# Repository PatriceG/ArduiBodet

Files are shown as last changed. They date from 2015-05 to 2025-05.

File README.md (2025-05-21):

# ArduiBodet	
Horloge mère pour Horloge de type *Bodet 1/2 Minute* pilotée par Arduino

Ce code nécessite les librairies suivantes:
  -DS3231 : [http://m5.img.dxcdn.com/CDDriver/CD/sku.222910.rar](http://m5.img.dxcdn.com/CDDriver/CD/sku.222910.rar)
  -Low-Power: [https://github.com/rocketscream/Low-Power] (https://github.com/rocketscream/Low-Power)
  
L'IDE utilisé est **AtmelStudio + VisualMicro** mais le code est compatible avec l'IDE Arduino.

Les détails de la construction de l'horloge mère sont donnés ici: [http://breizhmakers.over-blog.com/tag/horlogebodet/](http://breizhmakers.over-blog.com/tag/horlogebodet/)

# Les objectifs fixés sont: 

- Faible coût
- Alimentation 9V (nécessaire pour piloter l'horloge)
- Application automatique des changements d'heure.
- Très bonne stabilité de l'horloge (2 ppm soit environ 1 minute/an)
- Interrupteur Marche/Arrêt
- Interrupteur de mise en mode avance rapide pour mise à l'heure.

# Comment Flasher le Firmware

La plupart des ATMega328 sont livrés configurés pour fonctionner avec un quartz externe à 16MHz.

Avant de pouvoir flasher le firmware il faut donc installer l'ATMega sur une Breadboard en y câblant un quartz 16MHz et ses condensateurs associés, et y brancher le programmateur (j'utilise un USBAsp).

J'ai ensuite suivi [cette doc](https://www.electrosoftcloud.com/en/changing-the-arduino-clock-speed/) avec un IDE Arduino 1.8.18, mais cela fonctionne aussi avec l'IDE Arduino 2.x, pour configurer l'Arduino en mode horloge interne 1MHz (ou 8MHz, ça fonctionne aussi).

Une fois les définitions de Board MiniCore installées et choisi ATMega328 on a accès à tout un tas de settings, dont le mode de fonctionnement de l'horloge. 
Il reste ensuite à cliquer sur "Graver la séquence d'initialisation" pour flasher cette config de fuses (avec le programmateur choisi. J'utilise un USBAsp).

Il est ensuite conseillé de flasher le sketch Blink et de vérifier que la pin correspondant à D13 clignotte bien à 1 Hz

On peut alors flasher le sketch de l'Horloge.

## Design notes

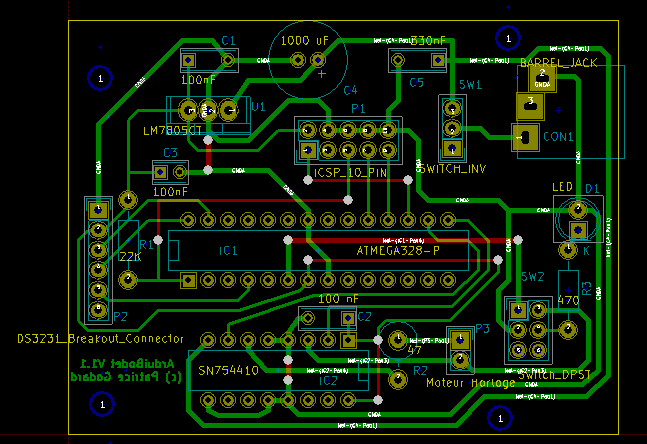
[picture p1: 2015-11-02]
doc/Screenshot du circuit.png

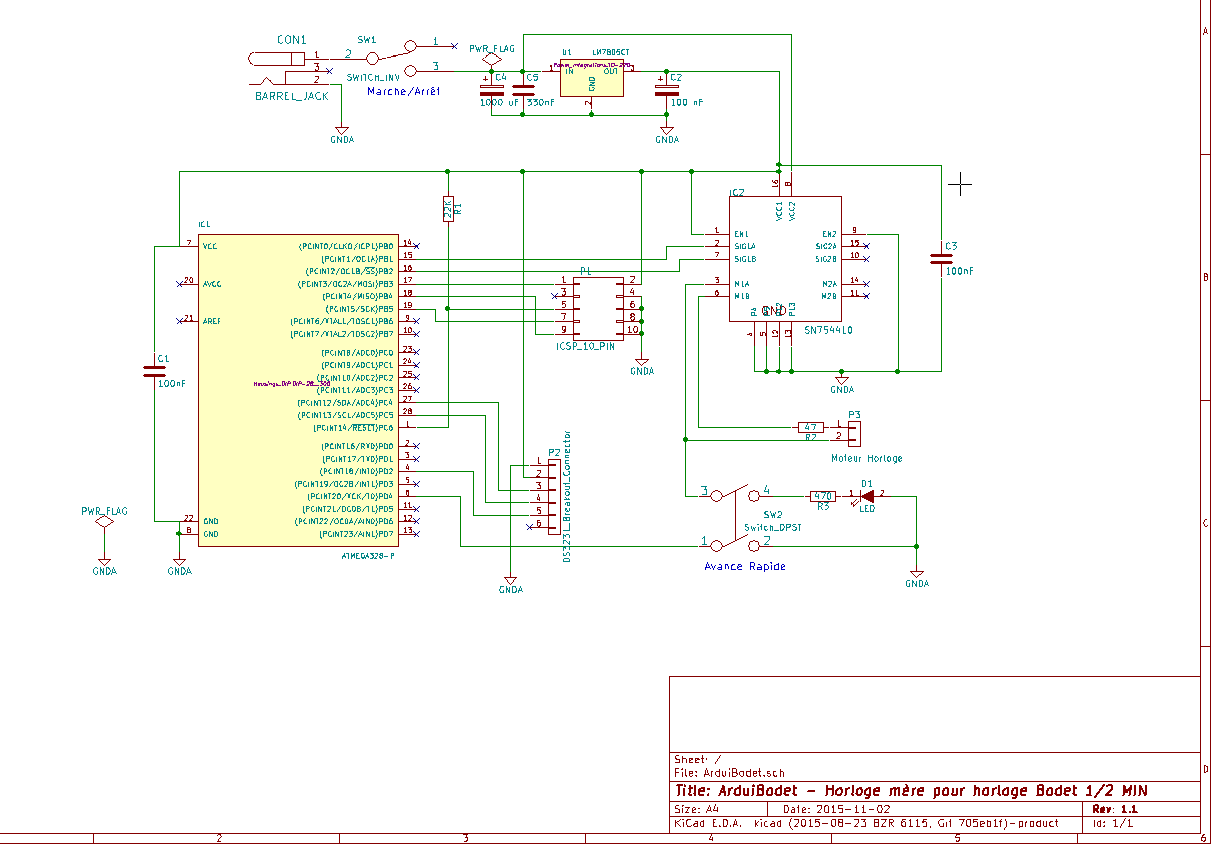
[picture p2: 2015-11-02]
doc/Screenshot du schéma.PNG

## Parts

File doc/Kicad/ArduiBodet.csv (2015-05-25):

Reference | Value | Footprint | Cost
IC1 | ATMEGA328-P | Housings_DIP:DIP-28__300
SW2 | Switch_DPST | myLib:Pin_Header_Straight_2x03_for_SPDT_switch
SW1 | SWITCH_INV | Pin_Headers:Pin_Header_Straight_1x03
R3 | 470 | Resistors_ThroughHole:Resistor_Horizontal_RM10mm
C1 | 100nF | Capacitors_ThroughHole:C_Rect_L4_W2.5_P2.5
C3 | 100nF | Capacitors_ThroughHole:C_Rect_L4_W2.5_P2.5
C2 | 100 nF | Capacitors_ThroughHole:C_Rect_L4_W2.5_P2.5
D1 | LED | LEDs:LED-5MM
R2 | 47 | Resistors_ThroughHole:Resistor_Vertical_RM5mm
P3 | Moteur Horloge | Socket_Strips:Socket_Strip_Straight_1x02
R1 | 22K | Resistors_ThroughHole:Resistor_Horizontal_RM10mm
CON1 | BARREL_JACK | myLib:BARREL_JACK_FR
P2 | DS3231_Breakout_Connector | Socket_Strips:Socket_Strip_Straight_1x05
P1 | ISP10PIN | Pin_Headers:Pin_Header_Straight_2x05
IC2 | SN754410 | Housings_DIP:DIP-16__300
U1 | LM7805CT | Power_Integrations:TO-220
C5 | 330nF | Capacitors_ThroughHole:C_Rect_L4_W2.5_P2.5
C4 | 1000 uF | Capacitors_Elko_ThroughHole:Elko_vert_20x10mm_RM2.5
 | Copper plate
 | Oxygen Peroxyde
 | Box
 |  |  | 0

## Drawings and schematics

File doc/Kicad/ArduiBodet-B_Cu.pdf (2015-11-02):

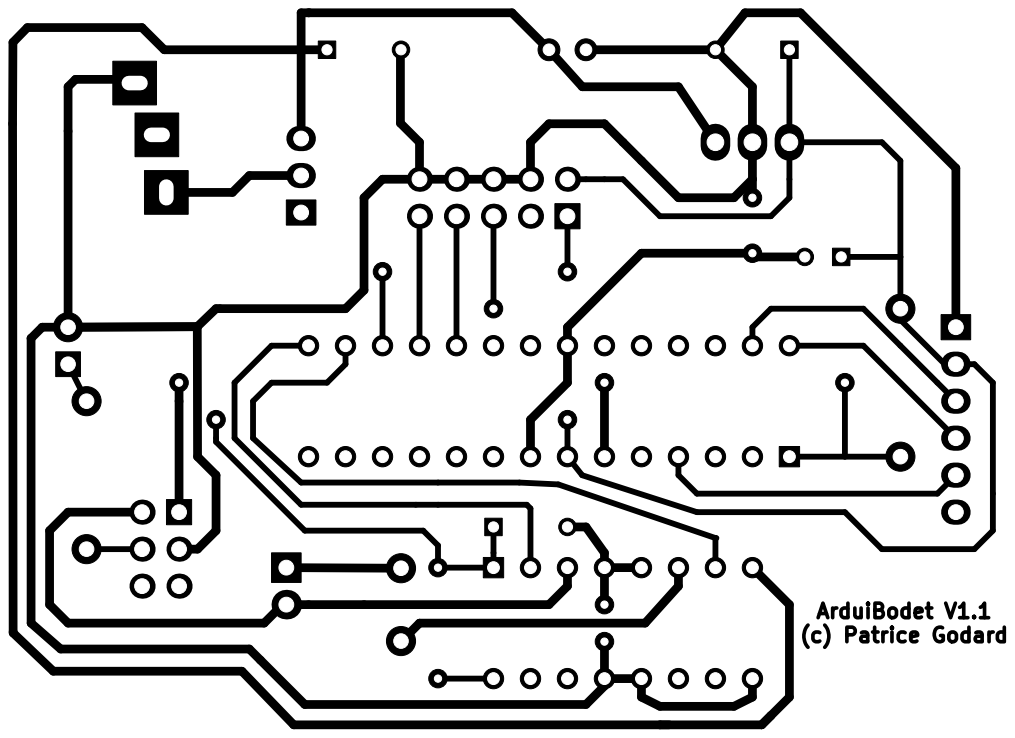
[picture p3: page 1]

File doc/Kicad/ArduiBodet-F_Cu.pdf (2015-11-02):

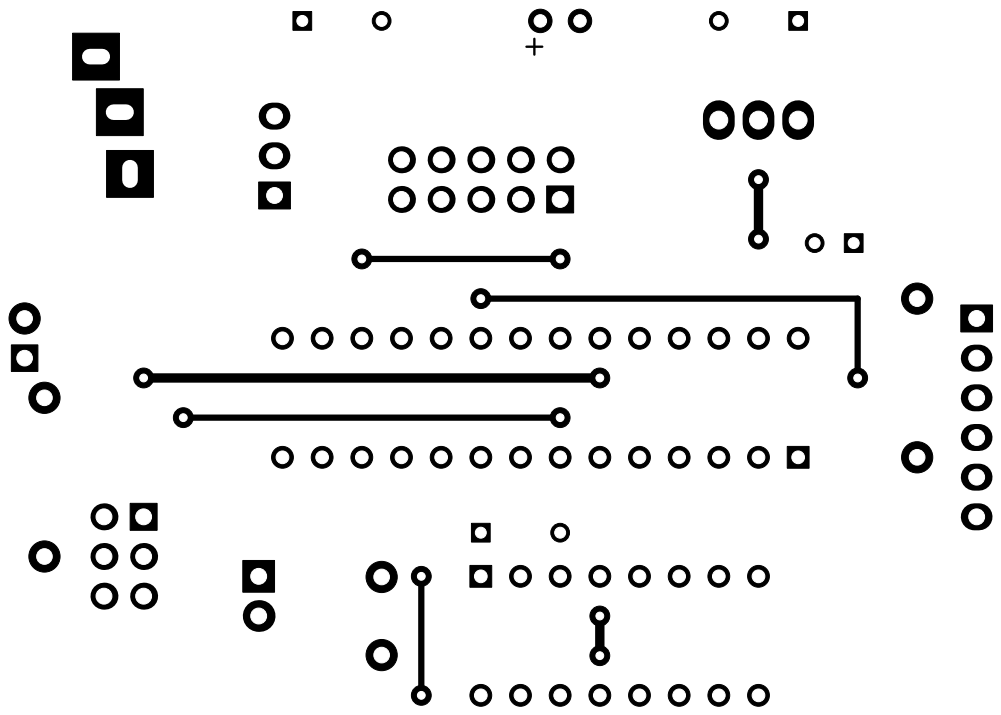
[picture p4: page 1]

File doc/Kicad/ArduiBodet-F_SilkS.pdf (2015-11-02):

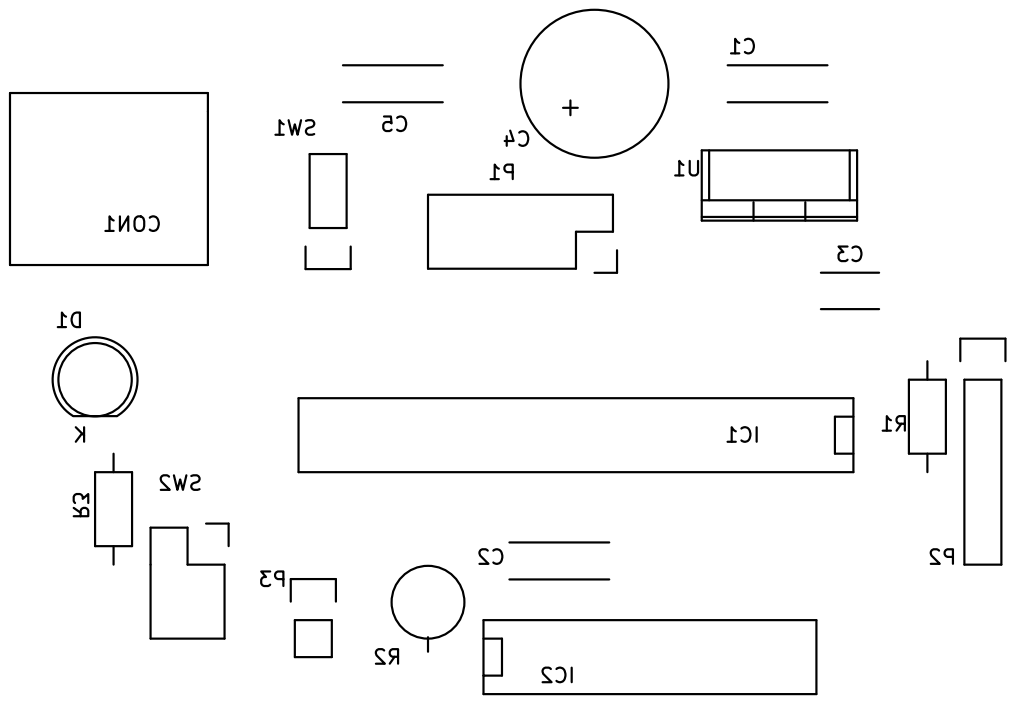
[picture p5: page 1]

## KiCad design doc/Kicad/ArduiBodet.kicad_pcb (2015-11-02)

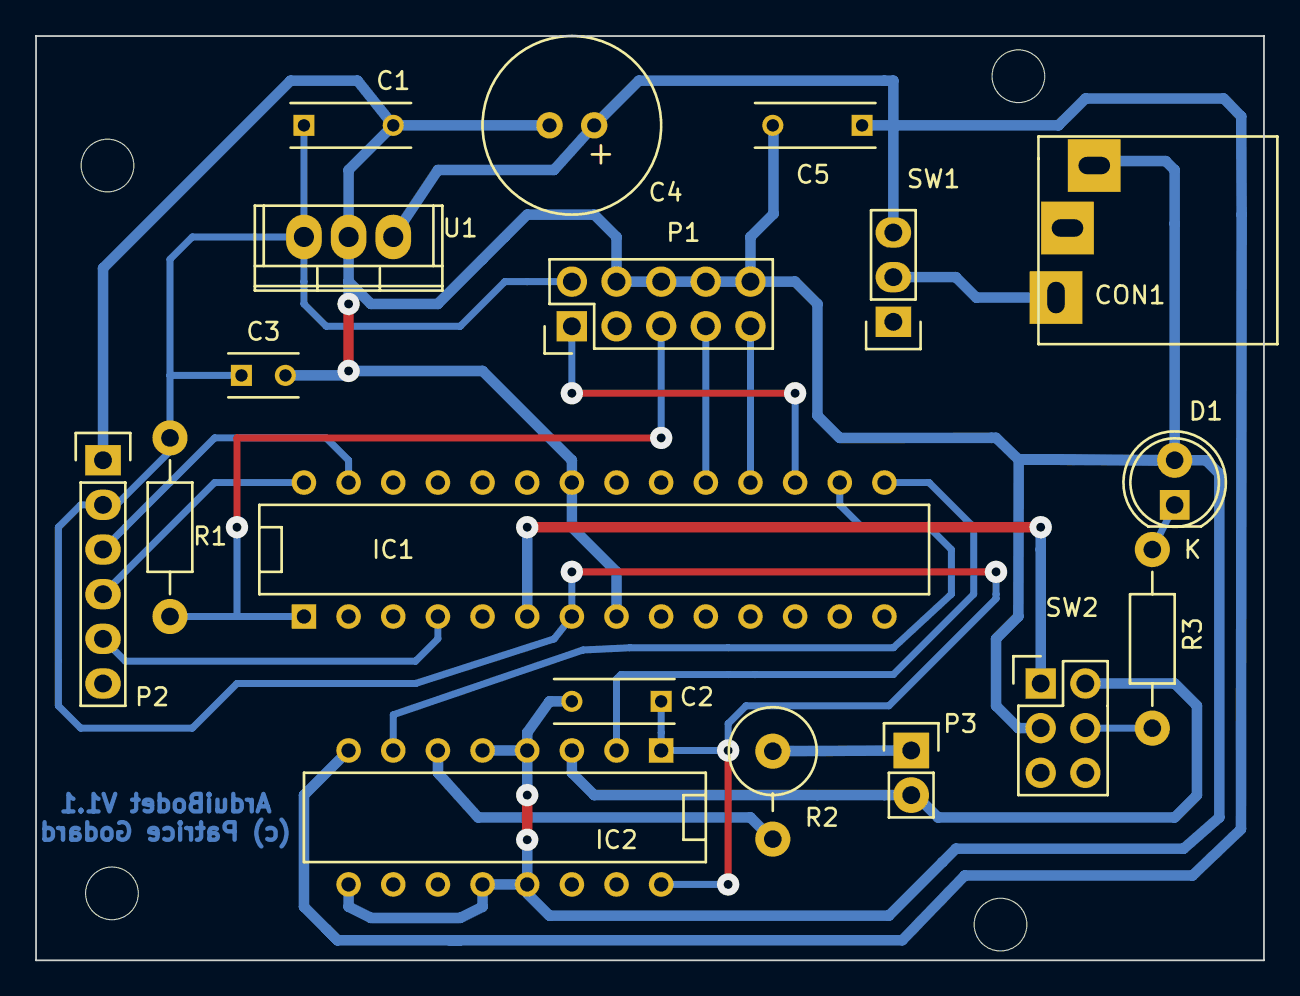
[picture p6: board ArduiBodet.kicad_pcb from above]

Board: 2 copper layers, 69.8 x 52.6 mm, 18 parts (0 on the bottom side), 19 nets.

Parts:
C1: 100nF; C_Rect_L7_W2.5_P2.5
C2: 100 nF; C_Rect_L7_W2.5_P2.5
C3: 100nF; C_Rect_L4_W2.5_P2.5
C4: 1000 uF; Elko_vert_20x10mm_RM2.5
C5: 330nF; C_Rect_L7_W2.5_P2.5
CON1: BARREL_JACK; BARREL_JACK_FR
D1: LED; LED-5MM
IC1: ATMEGA328-P; DIP-28__300
IC2: SN754410; DIP-16__300
P1: ICSP_10_PIN; Pin_Header_Straight_2x05
P2: DS3231_Breakout_Connector; Pin_Header_Straight_1x06
P3: Moteur Horloge; Pin_Header_Straight_1x02
R1: 22K; Resistor_Horizontal_RM10mm
R2: 47; Resistor_Vertical_RM5mm
R3: 470; Resistor_Horizontal_RM10mm
SW1: SWITCH_INV; Pin_Header_Straight_1x03
SW2: Switch_DPST; Pin_Header_Straight_2x03_for_SPDT_switch
U1: LM7805CT; TO-220

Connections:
GNDA: C1.2, C2.2, C3.2, C4.2, C5.2, CON1.2, D1.2, IC1.8, IC1.22, IC2.4, IC2.5, IC2.9, IC2.12, IC2.13, P1.4, P1.6, P1.8, P1.10, P2.1, SW2.2, U1.2
unnamed: C1.1, C2.1, C3.1, IC1.7, IC2.1, IC2.16, P1.2, P2.2, R1.1, U1.3
unnamed: C4.1, C5.1, IC2.8, SW1.3, U1.1
unnamed: CON1.1, SW1.2
unnamed: D1.1, R3.1
unnamed: IC1.1, P1.5, R1.2
unnamed: IC1.4, P2.5
unnamed: IC1.6, SW2.1
unnamed: IC1.15, IC2.2
unnamed: IC1.16, IC2.7
unnamed: IC1.17, P1.1
unnamed: IC1.18, P1.9
unnamed: IC1.19, P1.7
unnamed: IC1.27, P2.3
unnamed: IC1.28, P2.4
unnamed: IC2.3, P3.2, SW2.3
unnamed: IC2.6, R2.2
unnamed: P3.1, R2.1
unnamed: R3.2, SW2.4

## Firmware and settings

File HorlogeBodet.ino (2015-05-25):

#include <EEPROM.h>
#include <Wire.h>
#include "DS3231.h"
#include "LowPower.h"

//includes pour sleep mode
#include <avr/interrupt.h>
#include <avr/power.h>
#include <avr/sleep.h>
#include <avr/wdt.h>

//#define DEBUG_SERIAL 1

#if defined(__AVR_ATmega32U4__)
#define PIN_INTERRUPT 0
#define ID_INTERRUPT 2
#else
#define ID_INTERRUPT 0
#define PIN_INTERRUPT 2
#endif

#define PIN_1 9
#define PIN_2 10
#define PIN_FF 4

#define PULSE_WIDTH 400
#define PERIOD 1000
#define OFFSET_WINTER 3600
#define OFFSET_SUMMER 7200
#define OFFSET_ADDRESS 0
#define FAST_FORWARD_DELAY 400

//positive if clock is disabled (for specified number of cycles)
//used to disable clock for 1h during winter time change
uint8_t disabled = 0;
RTClib RTC;
DS3231 clock;
volatile uint8_t tickCounter=0;
//true if a tick interrupt has been received
volatile uint8_t tickReceived=0;

#ifdef DEBUG_SERIAL
void dumpTimestamp(char* msg){
	DateTime now = RTC.now();
	  Serial.print(now.year(), DEC);
	  Serial.print('/');
	  Serial.print(now.month(), DEC);
	  Serial.print('/');
	  Serial.print(now.day(), DEC);
	  Serial.print(' ');
	  Serial.print(now.hour(), DEC);
	  Serial.print(':');
	  Serial.print(now.minute(), DEC);
	  Serial.print(':');
	  Serial.print(now.second(), DEC);
	  Serial.print(' ');
	  Serial.println(msg);
}
#endif
/************************************************************************/
/* Wake-up interrupt routine                                            */
/************************************************************************/
void tick(){
	if(tickCounter == 0){
		tickReceived = true;
	}else{
		tickReceived = false;
	}
	
	tickCounter++;
	if(tickCounter == 30){
		tickCounter = 0;
	}
}

void setup() {
    Wire.begin();
	pinMode(PIN_1, OUTPUT);
	pinMode(PIN_2, OUTPUT);
	pinMode(PIN_FF,INPUT_PULLUP);
	pinMode(PIN_INTERRUPT, INPUT);   
	digitalWrite(PIN_1,LOW);
	digitalWrite(PIN_2,LOW);
#ifdef DEBUG_SERIAL	
	Serial.begin(9600);
#endif
     //init RTC
	 clock.enableOscillator(true,false,0); //enable 1Hz on SQW output
	 
	 DateTime now = RTC.now();
         if(now.year() == 2000){
			//first run or dead battery, reinit to compile time & date (time must be UTC!)
			//DateTime newDT = DateTime(__DATE__, __TIME__);
			//DateTime newDT = DateTime(2015,10,31,2,55);
			//DateTime newDT = DateTime(2015,10,25,0,55);
                        DateTime newDT = DateTime(2015,05,21,12,48);
			clock.setClockMode(false);	// set to 24h
		 	clock.setYear(newDT.year()-2000);
			clock.setMonth(newDT.month());
			clock.setDate(newDT.day());
			clock.setHour(newDT.hour());
			clock.setMinute(newDT.minute());
			clock.setSecond(newDT.second()); 
	 }
	 
	 attachInterrupt(ID_INTERRUPT, tick, RISING);
	 

	 #ifdef DEBUG_SERIAL
	 dumpTimestamp("starting loop");
	 #endif
}

/************************************************************************/
/* Send pulse to clock motor - pulse polarity is automatically inverted on each call  */
/************************************************************************/
void pulse(uint16_t pulseWidth)
{
	static uint8_t step = 0;
	uint8_t pin;
	if (step % 2 == 0){
		pin = PIN_1;
		}else{
		pin = PIN_2;
	}
	
	digitalWrite(pin,HIGH);
	delay(pulseWidth);
	digitalWrite(pin,LOW);	
	step++; 
}

/************************************************************************/
/* record time offset in eeprom                                         */
/************************************************************************/
void recordOffset(uint16_t offset)
{
	EEPROM.write(OFFSET_ADDRESS,offset & 0xFF);
	EEPROM.write(OFFSET_ADDRESS+1,(offset >> 8 ) & 0xFF);
}

/************************************************************************/
/* read time offset from eeprom                                         */
/************************************************************************/
uint16_t readOffset()
{
	uint16_t offset = EEPROM.read(OFFSET_ADDRESS) | (EEPROM.read(OFFSET_ADDRESS+1) << 8);
	return offset;
}

/************************************************************************/
/* Calculates DST change.
/* returns 0: no change necessary, 1: summer time change required, -1: winter time change required */
/************************************************************************/
int8_t calcDSTChange()
{
	int8_t change = 0;
	uint16_t currentOffset =  getCurrentTimeOffset();
	uint16_t previousOffset = readOffset();
	#ifdef DEBUG_SERIAL	
	Serial.print("currentOffset: ");
	Serial.println(currentOffset);
	Serial.print("previousOffset: ");
	Serial.println(previousOffset);
	#endif
	if(previousOffset != 0 && (previousOffset != currentOffset)){
		//change required
		recordOffset(currentOffset);
		if(currentOffset == OFFSET_SUMMER){
			change = +1;
		}else{
			if(currentOffset == OFFSET_WINTER){
				change = -1;
			}	
		}
	}
	return change;
}

uint16_t adjustDstEurope(DateTime t)
{
 /*You can use the following equations to calculate when DST starts and ends.
 The divisions are integer divisions, in which remainders are discarded.
 "mod" means the remainder when doing integer division, e.g., 20 mod 7 = 6.
 That is, 20 divided by 7 is 2 and 6/7th (where six is the remainder).
 With: y = year.
        For the United States:
            Begin DST: Sunday April (2+6*y-y/4) mod 7+1
            End DST: Sunday October (31-(y*5/4+1) mod 7)
           Valid for years 1900 to 2006, though DST wasn't adopted until the 1950s-1960s. 2007 and after:
            Begin DST: Sunday March 14 - (1 + y*5/4) mod 7
            End DST: Sunday November 7 - (1 + y*5/4) mod 7;
        European Economic Community:
            Begin DST: Sunday March (31 - (5*y/4 + 4) mod 7) at 1h U.T.
            End DST: Sunday October (31 - (5*y/4 + 1) mod 7) at 1h U.T.
            Since 1996, valid through 2099
(Equations by Wei-Hwa Huang (US), and Robert H. van Gent (EC))
 
 Adjustig Time with DST Europe/France/Paris: UTC+1h in winter, UTC+2h in summer
 
 */
 
  // last sunday of march
  int beginDSTDate=  (31 - (5* t.year() /4 + 4) % 7);
  //Serial.println(beginDSTDate);
  int beginDSTMonth=3;
  //last sunday of october
  int endDSTDate= (31 - (5 * t.year() /4 + 1) % 7);
  //Serial.println(endDSTDate);
  int endDSTMonth=10;
  // DST is valid as:
  if (((t.month() > beginDSTMonth) && (t.month() < endDSTMonth))
      || ((t.month() == beginDSTMonth) && (t.day() > beginDSTDate)) 
	  || ((t.month() == beginDSTMonth) && (t.day() == beginDSTDate) && (t.hour() >= 1))
      || ((t.month() == endDSTMonth) && (t.day() < endDSTDate))
	  || ((t.month() == endDSTMonth) && (t.day() == endDSTDate) && (t.hour() < 1)))
  return 7200;      // DST europe = utc +2 hour (summer time)
  else return 3600; // nonDST europe = utc +1 hour (winter time)
}


uint32_t getCurrentTimeOffset()
{
	DateTime now = RTC.now();
	uint32_t offset = adjustDstEurope(now);
	return offset;
}

/*********************************************************************************************/
/*  add 1h to the displayed time, and compensates for the time taken to move the clock hands */
/*********************************************************************************************/
void fastForwardToSummerTime(){
	detachInterrupt(PIN_INTERRUPT);
	for(int p=0;p<121;p++){
		pulse(PULSE_WIDTH);
		delay(FAST_FORWARD_DELAY);
	}
	attachInterrupt(ID_INTERRUPT, tick, RISING);
}

void loop() {
		unsigned long t1,t2;
		//fast-forward mode
		if(!digitalRead(PIN_FF)){
			detachInterrupt(PIN_INTERRUPT);
			do{
				pulse(PULSE_WIDTH);
				delay(FAST_FORWARD_DELAY);
			}while(!digitalRead(PIN_FF));
			tickCounter=1;
			attachInterrupt(ID_INTERRUPT, tick, RISING);
		}
	if(tickReceived){
		#ifdef DEBUG_SERIAL
		dumpTimestamp("tickReceived");
		#endif
		#ifdef DEBUG_SERIAL
		Serial.print("disabled: ");
		Serial.println(disabled);
		#endif
		int8_t changeRequired = calcDSTChange();
		#ifdef DEBUG_SERIAL
		Serial.print("changeRequired: ");
		Serial.println(changeRequired,DEC);
		#endif
		if(changeRequired == -1){
			disabled = 120; //2 cycles per min
		}else{
			if(changeRequired == 1){
				fastForwardToSummerTime();
			}
		}
		
		//check if DTS time change is required
		//TODO implement
		//if -1 -> disabled = 3600
		//if 1 -> fast-forward for 1h + delta secs (to be measured)
	
		//main loop
		if(disabled == 0){
			t1 = millis();
			pulse(PULSE_WIDTH);
			t2 = millis();
		}else{
			//updates are disabled
			disabled--;
		}
  }
	//delay(PERIOD-((t2-t1)));     	 
	// Enter power down state with ADC and BOD module disabled.
	// Wake up when wake up pin is rising
        //TODO set BOD_OFF after tests
	LowPower.powerDown(SLEEP_FOREVER, ADC_OFF, BOD_ON);  
	
	//LowPower.powerSave(SLEEP_FOREVER, ADC_OFF, BOD_ON,TIMER2_ON);  
	//LowPower.idle(SLEEP_FOREVER, ADC_OFF,TIMER4_ON,TIMER3_ON,	TIMER1_ON, TIMER0_ON,SPI_ON,USART1_ON,TWI_ON,USB_ON);  
	//TODO supprimer apr�s tests
	pinMode(13,OUTPUT);
	digitalWrite(13,HIGH);
	delay(25);
	digitalWrite(13,LOW);
}

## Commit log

2015-05-01 added schematics (work-in-progress)
    [ArduiBodet.dsn, ArduiBodet.kicad_pcb, ArduiBodet.sch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]
2015-05-01 DS3231, driving by external interrupts & DST changes seem OK on an Arduino Uno (ATMega 328)
2015-05-03 reset pulse width to 400ms.
    [HorlogeBodet.ino]
2015-05-04 routing in progress
    [ArduiBodet.dsn, ArduiBodet.kicad_pcb, ArduiBodet.sch]
2015-05-07 fully routed #1 fixed custom BARREL_JACK_FR.kicad_mod
    [ArduiBodet.kicad_pcb]
2015-05-08 routing almost done
    [ArduiBodet.kicad_pcb, ArduiBodet.sch]
2015-05-10 routing done. needs proof-checking
    [ArduiBodet.kicad_pcb, ArduiBodet.sch]
2015-05-20 don't remember :)
    [ArduiBodet.csv, ArduiBodet.sch]
2015-05-25 typon terminé et vérifié correction empreinte BARREL_JACK_FR
    [ArduiBodet.csv, ArduiBodet.kicad_pcb]
2015-05-25 fix BARREL_JACK_FR.kicad_mod
    [ArduiBodet.kicad_pcb]
2015-11-02 Version 1.1. Typon amélioré (pads condos plus larges, espacements,...
    [ArduiBodet.kicad_pcb, ArduiBodet.sch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]
2025-05-21 ajout mention que ça fonctionne aussi avec l'IDE Arduino 2.x
